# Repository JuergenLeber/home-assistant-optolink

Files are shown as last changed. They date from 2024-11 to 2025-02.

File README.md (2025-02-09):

# Home-Assistant Optolink
Instructions to connect a Viessmann Optolink heating to Home-Assistant using a PoE powered WT32-ETH01 EVO board based on ESP32-C3

## Goals
- Get temperature and status information from a Viessmann heating with a "Vitotronic 200 KW1" controller
- Collect this information in Home-Assistant and e.g. trigger a push notification when the heating is in an error condition
- Integration to Home-Assistant via ESPHome as it's very convenient
- Ethernet connection because of bad wifi signal near the heating
- Ideally use PoE as there is no unused power outlet near my heating
- 3D printed case that perfectly fits the electronic and of course also fits to the Optolink connector of the heating

## Needed hardware
- WT32-ETH01 EVO (or ETH01 EVO) based on an ESP32-C3 board with additional PoE module (e.g. from [AliExpress](https://de.aliexpress.com/item/1005006520809270.html))

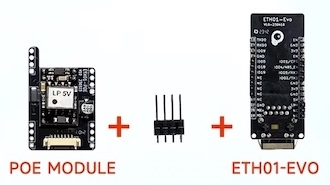
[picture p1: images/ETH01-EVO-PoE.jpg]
ETH01-EVO PoE
  

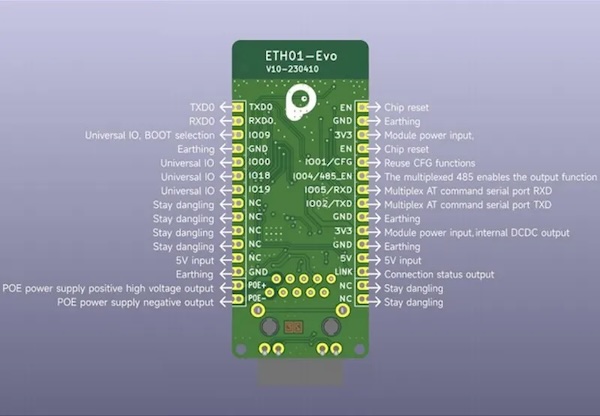
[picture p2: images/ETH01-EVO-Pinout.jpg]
ETH01-EVO Pinout
  

  Of course you can also use the ETH01-EVO without the PoE extension but then you need to power the module separately.
- Optolink circuit based on these [instructions](https://github.com/openv/openv/wiki/ESPHome-Optolink) with the following parts:
   - Photo transistor SFH-309 FA (e.g. from [Reichelt](https://www.reichelt.de/fototransistor-npn-730-1120nm-24-tht-3mm-sfh-309-fa-p60553.html))
   - Infrared led L-7104SF4BT KB (originally SIR-204 EVL which I couldn't get) (e.g. from [Reichelt](https://www.reichelt.de/infrarot-diode-gaalas-880-nm-50-3-mm-t1-l-7104sf4bt-kb-p216819.html))
   - Resistor 180Ω/220Ω (whatever you have) for the infrared led (e.g. from [Reichelt](https://www.reichelt.de/widerstand-kohleschicht-180-ohm-0207-250-mw-5--1-4w-180-p1362.html))
   - Resistor 10kΩ for the photo transistor (e.g. from [Reichelt](https://www.reichelt.de/widerstand-kohleschicht-10-kohm-0207-250-mw-5--1-4w-10k-p1338.html))
   - Some wires to connect the circuit together
   
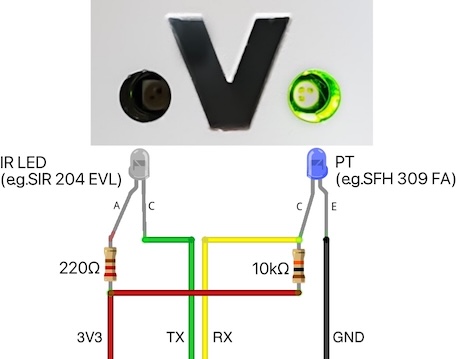
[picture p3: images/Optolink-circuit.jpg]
Optolink circuit
   

    ATTENTION: The mentioned photo transistors and diodes have the anode on the longer leg and the cathode on the shorter leg with the flattened side of the led case except the L-7104SF4BT KB which doesn't have a flattened side.

- 3D printed case that fits the ETH01-EVO including PoE module, the photo transistor and the IR led.

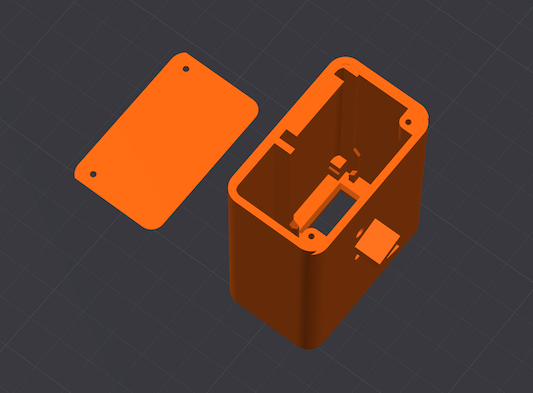
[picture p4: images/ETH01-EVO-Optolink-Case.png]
ETH01-EVO-Case
  

  The design is based on the [WT32-ETH01 Enclosure](https://www.thingiverse.com/thing:5621092) from [ledhed_jgh](https://www.thingiverse.com/ledhed_jgh). 

  You can find the STL files for the case [here](files/ETH01-EVO-Optolink-Case.stl) and for the lid [here](files/ETH01-EVO-Optolink-Case-lid.stl). It prints very well with normal PLA but needs supports because of the "V" connector.

- Two countersunk screws M2x7 to hold the lid on the case

## Prerequisites
- A 3D printer to print the case
- Basic soldering skills
- Some electronic knowledge (plus, minus, anode, cathode, etc.)
- A Home-Assistant installation with the newest ESPHome (2024.10.2 as of writing)

## Hardware installation
- ***IMPORTANT***: Don't solder the pin headers that came with the ETH01-EVO yet as they have to be soldered differently than in the images from the sellers and the device has to be programmed first!
- Use a standard USB<->TTL converter (e.g. with FTDI232 or similar). Make sure that it can provide **3,3V and not 5V** and connect as follows (see also pinout above):
  | Converter | -> | ETH01-EVO | 
  |-|-|-|
  | RX | -> | TXD0 |
  | TX | -> | RXD0 |
  | 3V3 | -> | 3V3 |
  | GND | -> | GND |
  | open | -> | EN |
  | open | -> | IO09 |

  It's best to use some breadboard jumper wires that can just be connected without soldering. Use a rubber band to hold them in contact.

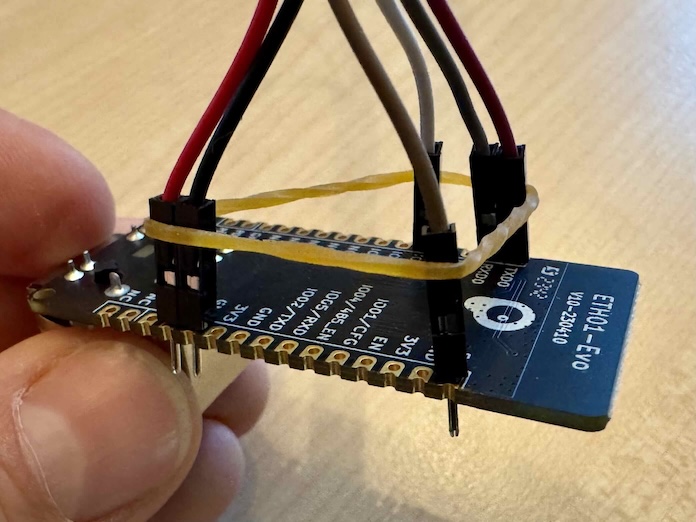
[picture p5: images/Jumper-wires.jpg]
Jumper wires connected
  

  To start the ETH01-EVO in boot mode it is necessary to connect "IO09" (yes, really - normally it's IO0 with ESP32s) with GND and then to reset the board shortly connect "EN" to GND for a quarter of a second. After programming you need to remove the connection from "IO09" to GND and do a reset manually again. 

  At this point you should skip over to the software installation part and install the device (with ethernet connected) in ESPHome to test if it is working at all. If that worked just go on here.

- Now that we know the module works we can solder the PoE module. Just disconnect all jumper wires and solder as in the image below:

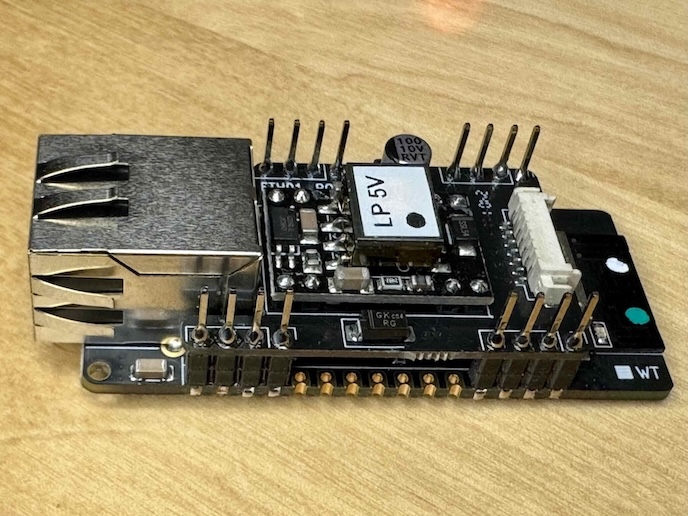
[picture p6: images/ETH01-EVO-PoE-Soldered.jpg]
  

  Only if it is soldered that way it will fit in the case later!

- Manufacture the "Optolink circuit" and connect as follows (cable colors used from circuit above):
  | Circuit | -> | ETH01-EVO | 
  |-|-|-|
  | RED | -> | 3V3 |
  | BLACK | -> | GND |
  | GREEN | -> | TXD (NOT TXD0!) |
  | YELLOW | -> | RXD (NOT RXD0!) |
  
  It is important to use the second hardware UART (IO05 RXD, IO02 TXD) for the circuit as there seems to be a problem in ESPHome using the default serial port with the strange connection parameters with two stop bits.

  To make the soldering easier you can 3D print the single [Optolink Adapter](files/Optolink-Adapter.stl) I used to test if everyting fits. Here you can solder all parts together and later just put in the real case as there isn't enough space to solder it right there.

  You can also use jumper wires here. Even with the soldered PoE module they will exactly fit in the 3D printed case later.

- Put everything in the 3D printed case. If the photo transistor or the IR led don't hold in place just use some hot glue from behind to fix them. Test everything before you close the lid and mount the screws.

## Software installation
- In ESPHome you can start with the following template:
```yaml
esphome:
  name: heating-optolink
  friendly_name: heating-optolink
  build_path: esp32
  platformio_options:
    upload_speed: 115200

esp32:
  board: esp32-c3-devkitm-1
  variant: esp32c3
  framework:
    type: esp-idf

external_components:
  - source:
      type: git
      url: https://github.com/JuergenLeber/esphome
      ref: dm9051
    components:
      - ethernet
    refresh: 0s
  - source: 
      type: git
      url: https://github.com/JuergenLeber/esphome_vitoconnect
      ref: master
    refresh: 0s
      
ethernet:
  type: DM9051
  clk_pin: GPIO07
  mosi_pin: GPIO10
  miso_pin: GPIO03
  cs_pin: GPIO09
  interrupt_pin: GPIO08
  reset_pin: GPIO06
  clock_speed: 8MHz  

logger:
  hardware_uart: UART0
  level: DEBUG

uart:
  - id: uart_vitoconnect
    rx_pin: GPIO05
    tx_pin: GPIO02
    baud_rate: 4800
    data_bits: 8
    parity: EVEN
    stop_bits: 2

vitoconnect:
  uart_id: uart_vitoconnect
  protocol: KW
  update_interval: 30s

sensor:
  - platform: vitoconnect
    name: "Außentemperatur"
    address: 0x0800
    length: 2
    unit_of_measurement: "°C"
    accuracy_decimals: 1
    filters:
      - multiply: 0.1
    device_class: temperature
  - platform: vitoconnect
    name: "Kesseltemperatur"
    address: 0x0802
    length: 2
    unit_of_measurement: "°C"
    accuracy_decimals: 1
    filters:
      - multiply: 0.1
    device_class: temperature
  - platform: vitoconnect
    name: "Speichertemperatur"
    address: 0x0804
    length: 2
    unit_of_measurement: "°C"
    accuracy_decimals: 1
    filters:
      - multiply: 0.1
    device_class: temperature
  - platform: vitoconnect
    name: "Rücklauftemperatur"
    address: 0x080A
    length: 2
    unit_of_measurement: "°C"
    accuracy_decimals: 1
    filters:
      - multiply: 0.1
    device_class: temperature
  - platform: vitoconnect
    name: "Vorlauftemperatur"
    address: 0x080C
    length: 2
    unit_of_measurement: "°C"
    accuracy_decimals: 1
    filters:
      - multiply: 0.1
    device_class: temperature
  - platform: vitoconnect
    name: "Vorlaufsolltemperatur"
    address: 0x2544
    length: 2
    unit_of_measurement: "°C"
    accuracy_decimals: 1
    filters:
      - multiply: 0.1
    device_class: temperature
  - platform: vitoconnect
    name: "Kesselsolltemperatur"
    address: 0x555A
    length: 2
    unit_of_measurement: "°C"
    accuracy_decimals: 1
    filters:
      - multiply: 0.1
    device_class: temperature
  - platform: vitoconnect
    name: "Brennerstarts"
    address: 0x088A
    length: 4
    unit_of_measurement: ""
  - platform: vitoconnect
    name: "Brennerbetriebsstunden Stufe 1"
    address: 0x08A7
    length: 4
    unit_of_measurement: "s"
    device_class: duration
  - platform: vitoconnect
    name: "Brennerbetriebsstunden Stufe 2"
    address: 0x08AB
    length: 4
    unit_of_measurement: "s"
    device_class: duration
  - platform: vitoconnect
    name: "Ölverbrauch"
    address: 0x7574
    length: 4
    unit_of_measurement: "l"
    accuracy_decimals: 3
    filters:
      - multiply: 0.001
    device_class: volume
  - platform: vitoconnect
    name: "Betriebsart"
    address: 0x2301
    length: 1
  - platform: vitoconnect
    name: "Heizkennlinie Niveau"
    address: 0x2304
    length: 1
  - platform: vitoconnect
    name: "Heizkennlinie Neigung"
    address: 0x2305
    length: 1
    accuracy_decimals: 1
    filters:
      - multiply: 0.1
  - platform: vitoconnect
    name: "Raumtemperatur Soll"
    address: 0x2306
    length: 1
    unit_of_measurement: "°C"
    accuracy_decimals: 1
    device_class: temperature

binary_sensor:
  - platform: vitoconnect
    name: "Störung"
    address: 0x0883
  - platform: vitoconnect
    name: "Heizkreispumpe"
    address: 0x250A
  - platform: vitoconnect
    name: "Warmwasserfreigabe"
    address: 0x2508

api:
  encryption:
    key: "<KEY>"

ota:
  - platform: esphome
    password: "<PASSWORD>"
```
  As the current ESPHome (2024.10.2 as of writing) doesn't support the ethernet chip on the ETH01-EVO yet this component has to be sourced from an external repository.

  Same for the [Vitoconnect component](https://github.com/dannerph/esphome_vitoconnect) which hasn't made it to the official repositories yet. It is currently linked to my fork as I repaired the KW protocol of the component. 

- For additional devices, values and other protocols (I only tested the KW protocol here) please see the documentation from the [openv](https://github.com/openv) project:
   - [Devices supported](https://github.com/openv/openv/wiki/Geräte)
   - [Addresses to read/write values](https://github.com/openv/openv/wiki/Adressen)
   - [Protocols](https://github.com/openv/openv/wiki/Protokolle)

## Finalization
- Finally you can mount the whole "thing" to your heating and connect to a PoE capable switch or router. Alternatively you can use a PoE injector (e.g. a cheap Ubiquiti POE-AF from [Amazon](https://www.amazon.de/AP-Acc-Ubiquiti-U-POE-AF-Injektor/dp/B07FB72GJ3)). Mounted to the heating it will look like this:

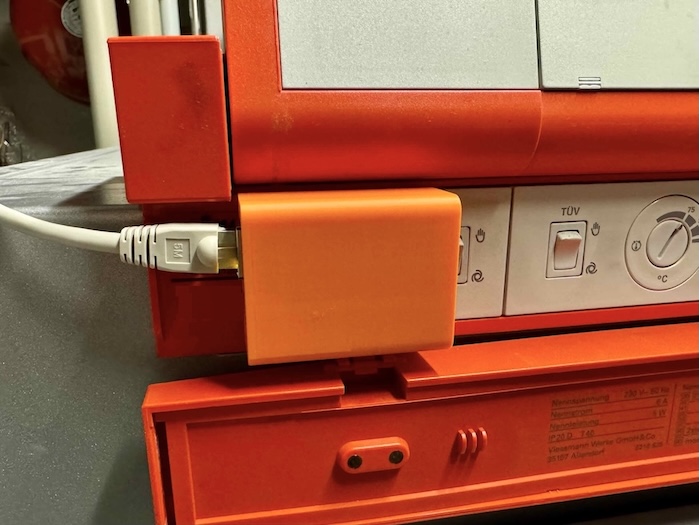
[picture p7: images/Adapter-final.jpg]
Mounted adapter
  

- In Home-Assistant the device will then display the configured values:
  
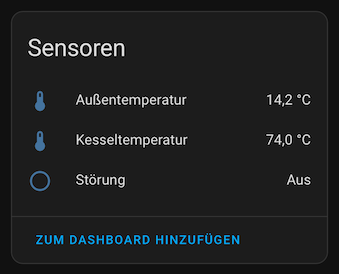
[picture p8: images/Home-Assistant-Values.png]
Home-Assistant values
  

## Thank you!
You've made it to the end, hopefully you'll have fun rebuilding the whole thing. 
In case of any questions feel free to contact me!

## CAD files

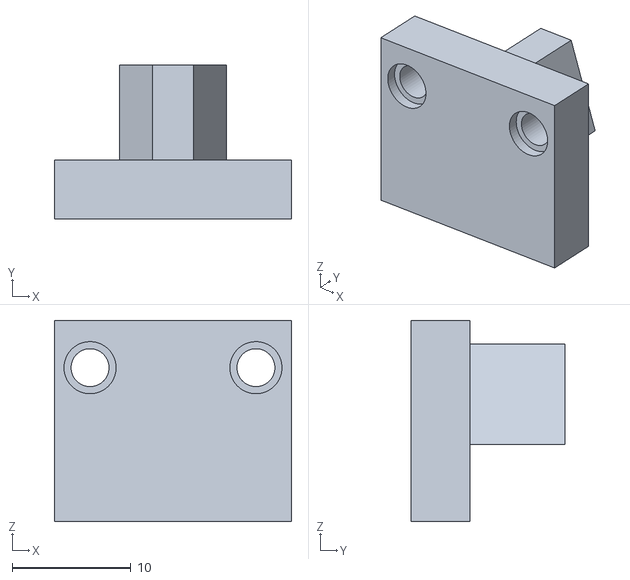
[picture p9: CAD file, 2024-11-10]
files/Optolink-Adapter.stl
20.0 x 13.0 x 17.0

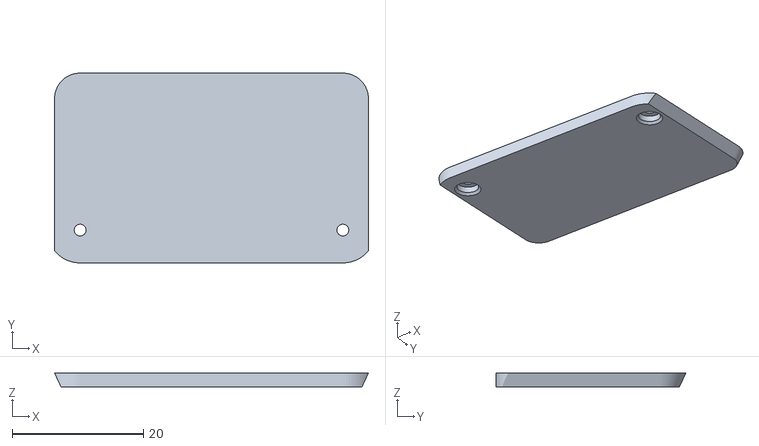
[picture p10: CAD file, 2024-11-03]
files/ETH01-EVO-Optolink-Case-lid.stl
47.8 x 28.9 x 2.15

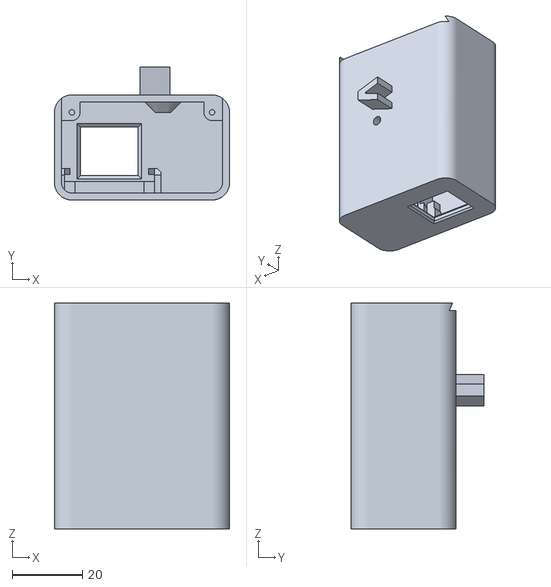
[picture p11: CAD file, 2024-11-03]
files/ETH01-EVO-Optolink-Case.stl
50.0 x 38.0 x 64.5

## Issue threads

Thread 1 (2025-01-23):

Error uart

YannGranger, 2025-01-23:
Hello,
thanks you for you work.

i have those continuous debug messages.
And no information are gathered by the esp32 frome the boilier.
I suspect th infrared LED and transistor LED not capturing any datas.

Can you point me in the correct direction to solve this issue ?

[17:35:33][D][uart_debug:114]: >>> 04
[17:35:34][E][uart:015]: Reading from UART timed out at byte 0!
[17:35:34][W][component:204]: Component vitoconnect took a long time for an operation (0.10 s).
[17:35:34][W][component:205]: Components should block for at most 20-30ms.
[17:35:34][E][uart:015]: Reading from UART timed out at byte 0!
[17:35:34][W][component:204]: Component vitoconnect took a long time for an operation (0.11 s).
[17:35:34][W][component:205]: Components should block for at most 20-30ms.
[17:35:34][E][uart:015]: Reading from UART timed out at byte 0!
[17:35:34][W][component:204]: Component vitoconnect took a long time for an operation (0.11 s).
[17:35:34][W][component:205]: Components should block for at most 20-30ms.
[17:35:34][E][uart:015]: Reading from UART timed out at byte 0!
[17:35:34][W][component:204]: Component vitoconnect took a long time for an operation (0.11 s).
[17:35:34][W][component:205]: Components should block for at most 20-30ms.
[17:35:34][E][uart:015]: Reading from UART timed out at byte 0!
[17:35:34][W][component:204]: Component vitoconnect took a long time for an operation (0.11 s).
[17:35:34][W][component:205]: Components should block for at most 20-30ms.
[17:35:34][E][uart:015]: Reading from UART timed out at byte 0!
[17:35:34][W][component:204]: Component vitoconnect took a long time for an operation (0.11 s).
[17:35:34][W][component:205]: Components should block for at most 20-30ms.
[17:35:34][E][uart:015]: Reading from UART timed out at byte 0!
[17:35:34][W][component:204]: Component vitoconnect took a long time for an operation (0.11 s).
[17:35:34][W][component:205]: Components should block for at most 20-30ms.
[17:35:35][E][uart:015]: Reading from UART timed out at byte 0!
[17:35:35][W][component:204]: Component vitoconnect took a long time for an operation (0.11 s).
[17:35:35][W][component:205]: Components should block for at most 20-30ms.
[17:35:35][D][uart_debug:114]: >>> 04

JuergenLeber, 2025-02-08:
Sorry for the late answer - didn't get a notification for that issue via email.

So first of all you should make sure that your circuit is built correctly. Just look at the IR LED with a smartphone camera and you should see it blinking slightly (it's not really bright but you can see it). This is because the heating will only send data after it received the command to do so.

Which UART are you using for the circuit? Or did you build everything as in my instructions?

YannGranger, 2025-02-09:
hello and thank you for your answer.
I've repaired the circuit. The TX LED was in the wrong polarity.
I can see it blinking through my smartphone camera : all good
The RX is also working fine. I've tested send a character chain from the TX LED to the RX LED.
THe LEDs need to be very well aligned for the communication to be transferred.

I've check on the boiled but no luck. Still the same messages. I think the LEDs are not very well aligned with the boiler LEDs.
What do you think ?

JuergenLeber, 2025-02-10:
Which UART are you using? Or which pins are you using for the circuit?
It has to be
```yaml
uart:
  - id: uart_vitoconnect
    rx_pin: GPIO05
    tx_pin: GPIO02
    baud_rate: 4800
    data_bits: 8
    parity: EVEN
    stop_bits: 2
```
The other UART on pins 20 and 21 won't work. And in addition to that there is a strange behavior of ESPHome with these "strange" serial parameters which leads to serial debugging not working correctly and showing the wrong bytes (probably because of the 2 stop bits).

I also updated the template in the readme that will also work with newer ESPHome versions. Probably give it a try to be sure it's not a configuration issue.

If you're using the LEDs I mentioned they will work if you are using the 3D printed housing. Otherwise too much light from around will disturb the communication.

JuergenLeber, 2025-02-19:
Have you been able to have a look or to solve the issue @YannGranger?

Closed 2025-02-26.

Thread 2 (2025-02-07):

Failed config

andyenns, 2025-02-07:
Hi,
i'm getting en error when i try to install the code via ESPhome

INFO ESPHome 2024.12.4
INFO Reading configuration /config/esphome/optolink-heating.yaml...
Failed config

external_components: [source /config/esphome/optolink-heating.yaml:17]
  - source:
      type: git
      url: https://github.com/JuergenLeber/esphome
      ref: dm9051

      [components] is an invalid option for [source]. Please check the indentation.
      components:
        - ethernet

      [refresh] is an invalid option for [source]. Did you mean [ref]?
      refresh: 0s
  - source:
      type: git
      url: https://github.com/JuergenLeber/esphome_vitoconnect

can you please help?
Thanks!

JuergenLeber, 2025-02-08:
Oh, seems like the markdown destroyed some of the tab indentations. Will fix that in the readme. Until then just take this one:

`esphome:
  name: heating-optolink
  friendly_name: heating-optolink
  build_path: esp32
  platformio_options:
    upload_speed: 115200

esp32:
  board: esp32-c3-devkitm-1
  variant: esp32c3
  framework:
    type: esp-idf
    version: latest
    platform_version: 6.5.0

external_components:
  - source:
      type: git
      url: https://github.com/JuergenLeber/esphome
      ref: dm9051
    components:
      - ethernet
    refresh: 0s
  - source:
      type: git
      url: https://github.com/JuergenLeber/esphome_vitoconnect
      ref: master
    refresh: 0s

ethernet:
  type: DM9051
  clk_pin: GPIO07
  mosi_pin: GPIO10
  miso_pin: GPIO03
  cs_pin: GPIO09
  interrupt_pin: GPIO08
  reset_pin: GPIO06
  clock_speed: 8MHz

logger:
  hardware_uart: UART0
  level: DEBUG

uart:
  - id: uart_vitoconnect
    rx_pin: GPIO05
    tx_pin: GPIO02
    baud_rate: 4800
    data_bits: 8
    parity: EVEN
    stop_bits: 2

vitoconnect:
  uart_id: uart_vitoconnect
  protocol: KW
  update_interval: 30s

sensor:
  - platform: vitoconnect
    name: "Außentemperatur"
    address: 0x0800
    length: 2
    unit_of_measurement: "°C"
    accuracy_decimals: 1
    filters:
      - multiply: 0.1
    device_class: temperature
  - platform: vitoconnect
    name: "Kesseltemperatur"
    address: 0x0802
    length: 2
    unit_of_measurement: "°C"
    accuracy_decimals: 1
    filters:
      - multiply: 0.1
    device_class: temperature
  - platform: vitoconnect
    name: "Speichertemperatur"
    address: 0x0804
    length: 2
    unit_of_measurement: "°C"
    accuracy_decimals: 1
    filters:
      - multiply: 0.1
    device_class: temperature
  - platform: vitoconnect
    name: "Rücklauftemperatur"
    address: 0x080A
    length: 2
    unit_of_measurement: "°C"
    accuracy_decimals: 1
    filters:
      - multiply: 0.1
    device_class: temperature
  - platform: vitoconnect
    name: "Vorlauftemperatur"
    address: 0x080C
    length: 2
    unit_of_measurement: "°C"
    accuracy_decimals: 1
    filters:
      - multiply: 0.1
    device_class: temperature
  - platform: vitoconnect
    name: "Vorlaufsolltemperatur"
    address: 0x2544
    length: 2
    unit_of_measurement: "°C"
    accuracy_decimals: 1
    filters:
      - multiply: 0.1
    device_class: temperature
  - platform: vitoconnect
    name: "Kesselsolltemperatur"
    address: 0x555A
    length: 2
    unit_of_measurement: "°C"
    accuracy_decimals: 1
    filters:
      - multiply: 0.1
    device_class: temperature
  - platform: vitoconnect
    name: "Brennerstarts"
    address: 0x088A
    length: 4
    unit_of_measurement: ""
  - platform: vitoconnect
    name: "Brennerbetriebsstunden Stufe 1"
    address: 0x08A7
    length: 4
    unit_of_measurement: "s"
    device_class: duration
  - platform: vitoconnect
    name: "Brennerbetriebsstunden Stufe 2"
    address: 0x08AB
    length: 4
    unit_of_measurement: "s"
    device_class: duration
  - platform: vitoconnect
    name: "Ölverbrauch"
    address: 0x7574
    length: 4
    unit_of_measurement: "l"
    accuracy_decimals: 3
    filters:
      - multiply: 0.001
    device_class: volume
  - platform: vitoconnect
    name: "Betriebsart"
    address: 0x2301
    length: 1
  - platform: vitoconnect
    name: "Heizkennlinie Niveau"
    address: 0x2304
    length: 1
  - platform: vitoconnect
    name: "Heizkennlinie Neigung"
    address: 0x2305
    length: 1
    accuracy_decimals: 1
    filters:
      - multiply: 0.1
  - platform: vitoconnect
    name: "Raumtemperatur Soll"
    address: 0x2306
    length: 1
    unit_of_measurement: "°C"
    accuracy_decimals: 1
    device_class: temperature

binary_sensor:
  - platform: vitoconnect
    name: "Störung"
    address: 0x0883
  - platform: vitoconnect
    name: "Heizkreispumpe"
    address: 0x250A
  - platform: vitoconnect
    name: "Warmwasserfreigabe"
    address: 0x2508

api:
  encryption:
    key: "<KEY>"

ota:
  - platform: esphome
    password: "<PASSWORD>"`

andyenns, 2025-02-08:
Thank you for the quick response. I tried it with the right indentations and now i get the following error:

INFO ESPHome 2024.12.4
INFO Reading configuration /config/esphome/optolink.yaml...
INFO Updating https://github.com/JuergenLeber/esphome@dm9051
INFO Updating https://github.com/JuergenLeber/esphome_vitoconnect@master
Failed config

esp32: [source /config/esphome/optolink.yaml:9]
  board: esp32-c3-devkitm-1
  variant: esp32c3

  ESP-IDF 5.1.5 not supported by platformio/espressif32.
  framework:
    type: esp-idf
    version: latest
    platform_version: 6.5.0

Is there a specific version and platform_version i should use?

JuergenLeber, 2025-02-09:
That one should work (at least works here with newest ESPHome):

```yaml
esphome:
  name: heating-optolink
  friendly_name: heating-optolink
  build_path: esp32
  platformio_options:
    upload_speed: 115200

esp32:
  board: esp32-c3-devkitm-1
  variant: esp32c3
  framework:
    type: esp-idf

external_components:
  - source:
      type: git
      url: https://github.com/JuergenLeber/esphome
      ref: dm9051
    components:
      - ethernet
    refresh: 0s
  - source:
      type: git
      url: https://github.com/JuergenLeber/esphome_vitoconnect
      ref: master
    refresh: 0s

ethernet:
  type: DM9051
  clk_pin: GPIO07
  mosi_pin: GPIO10
  miso_pin: GPIO03
  cs_pin: GPIO09
  interrupt_pin: GPIO08
  reset_pin: GPIO06
  clock_speed: 8MHz

logger:
  hardware_uart: UART0
  level: DEBUG

uart:
  - id: uart_vitoconnect
    rx_pin: GPIO05
    tx_pin: GPIO02
    baud_rate: 4800
    data_bits: 8
    parity: EVEN
    stop_bits: 2

vitoconnect:
  uart_id: uart_vitoconnect
  protocol: KW
  update_interval: 30s

sensor:
  - platform: vitoconnect
    name: "Außentemperatur"
    address: 0x0800
    length: 2
    unit_of_measurement: "°C"
    accuracy_decimals: 1
    filters:
      - multiply: 0.1
    device_class: temperature
  - platform: vitoconnect
    name: "Kesseltemperatur"
    address: 0x0802
    length: 2
    unit_of_measurement: "°C"
    accuracy_decimals: 1
    filters:
      - multiply: 0.1
    device_class: temperature
  - platform: vitoconnect
    name: "Speichertemperatur"
    address: 0x0804
    length: 2
    unit_of_measurement: "°C"
    accuracy_decimals: 1
    filters:
      - multiply: 0.1
    device_class: temperature
  - platform: vitoconnect
    name: "Rücklauftemperatur"
    address: 0x080A
    length: 2
    unit_of_measurement: "°C"
    accuracy_decimals: 1
    filters:
      - multiply: 0.1
    device_class: temperature
  - platform: vitoconnect
    name: "Vorlauftemperatur"
    address: 0x080C
    length: 2
    unit_of_measurement: "°C"
    accuracy_decimals: 1
    filters:
      - multiply: 0.1
    device_class: temperature
  - platform: vitoconnect
    name: "Vorlaufsolltemperatur"
    address: 0x2544
    length: 2
    unit_of_measurement: "°C"
    accuracy_decimals: 1
    filters:
      - multiply: 0.1
    device_class: temperature
  - platform: vitoconnect
    name: "Kesselsolltemperatur"
    address: 0x555A
    length: 2
    unit_of_measurement: "°C"
    accuracy_decimals: 1
    filters:
      - multiply: 0.1
    device_class: temperature
  - platform: vitoconnect
    name: "Brennerstarts"
    address: 0x088A
    length: 4
    unit_of_measurement: ""
  - platform: vitoconnect
    name: "Brennerbetriebsstunden Stufe 1"
    address: 0x08A7
    length: 4
    unit_of_measurement: "s"
    device_class: duration
  - platform: vitoconnect
    name: "Brennerbetriebsstunden Stufe 2"
    address: 0x08AB
    length: 4
    unit_of_measurement: "s"
    device_class: duration
  - platform: vitoconnect
    name: "Ölverbrauch"
    address: 0x7574
    length: 4
    unit_of_measurement: "l"
    accuracy_decimals: 3
    filters:
      - multiply: 0.001
    device_class: volume
  - platform: vitoconnect
    name: "Betriebsart"
    address: 0x2301
    length: 1
  - platform: vitoconnect
    name: "Heizkennlinie Niveau"
    address: 0x2304
    length: 1
  - platform: vitoconnect
    name: "Heizkennlinie Neigung"
    address: 0x2305
    length: 1
    accuracy_decimals: 1
    filters:
      - multiply: 0.1
  - platform: vitoconnect
    name: "Raumtemperatur Soll"
    address: 0x2306
    length: 1
    unit_of_measurement: "°C"
    accuracy_decimals: 1
    device_class: temperature

binary_sensor:
  - platform: vitoconnect
    name: "Störung"
    address: 0x0883
  - platform: vitoconnect
    name: "Heizkreispumpe"
    address: 0x250A
  - platform: vitoconnect
    name: "Warmwasserfreigabe"
    address: 0x2508

api:
  encryption:
    key: "<KEY>"

ota:
  - platform: esphome
    password: "<PASSWORD>"
```

andyenns, 2025-02-09:
Now it seems to work. Thank you very much :)

Closed 2025-02-09.

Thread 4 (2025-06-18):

Feature Request: Add CAD Files (SolidWorks / Fusion 360) Alongside STL Files

Eric-D, 2025-06-18:
Hi,

First of all, thank you for this great project and for making it available to the community!

I’d like to propose the **addition of original CAD files** (e.g., SolidWorks .sldprt/.sldasm, Fusion 360 .f3d, or STEP .step) to the repository, alongside the existing STL files.

STL files are mesh-based and difficult to modify precisely. CAD files, on the other hand, are parametric and much easier to edit, making it easier for contributors and users to adapt parts to their specific needs.

In my case, I need to handle a 1 cm edge constraint for the V and the leds, which would be much easier to adjust directly in a parametric CAD model than with STL meshes. I'm sure i'm not the only one in that case.

Thank's in advance.

JuergenLeber, 2025-08-11:
I need to update some things anyway and then I'll also add the CAD files! Sorry for the late answer.

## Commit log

2024-11-03 feat: add first version of project documentation
    [ETH01-EVO-Optolink-Case-lid.stl, ETH01-EVO-Optolink-Case.stl]
2024-11-10 feat: add soldering help
    [Optolink-Adapter.stl]
2024-11-28 fix: use second UART for circuit
2025-11-08 feat: add Fusion file for the case
